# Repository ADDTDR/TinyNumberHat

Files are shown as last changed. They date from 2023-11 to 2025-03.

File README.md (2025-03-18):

# TinyNumberHat 

<!-- ![Alt text](TinyNumberHat_front.png)

![Alt text](TinyNumberHat_back.png)
  -->

Red ALS314         |  Green AL304V 
:-------------------------:|:-------------------------:
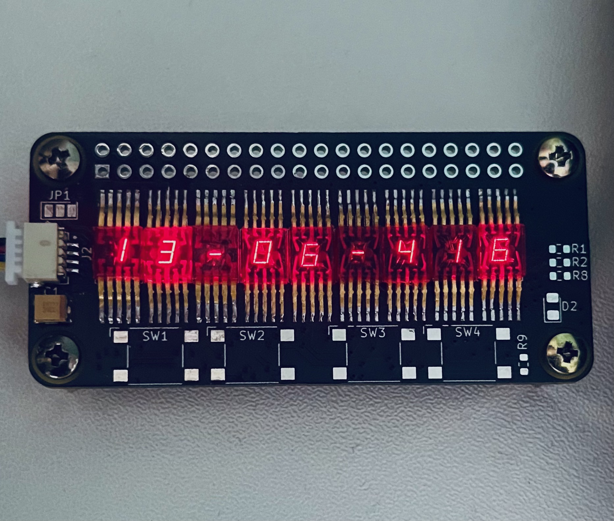
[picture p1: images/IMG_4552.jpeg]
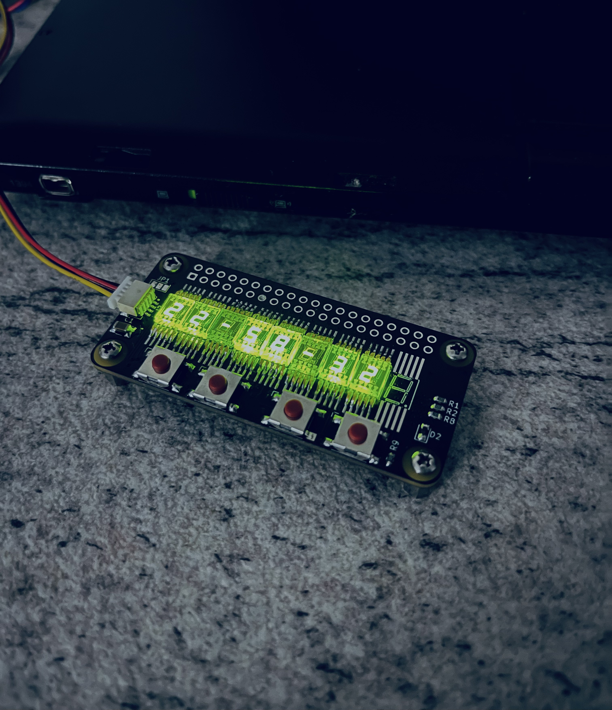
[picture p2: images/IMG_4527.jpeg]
  |  
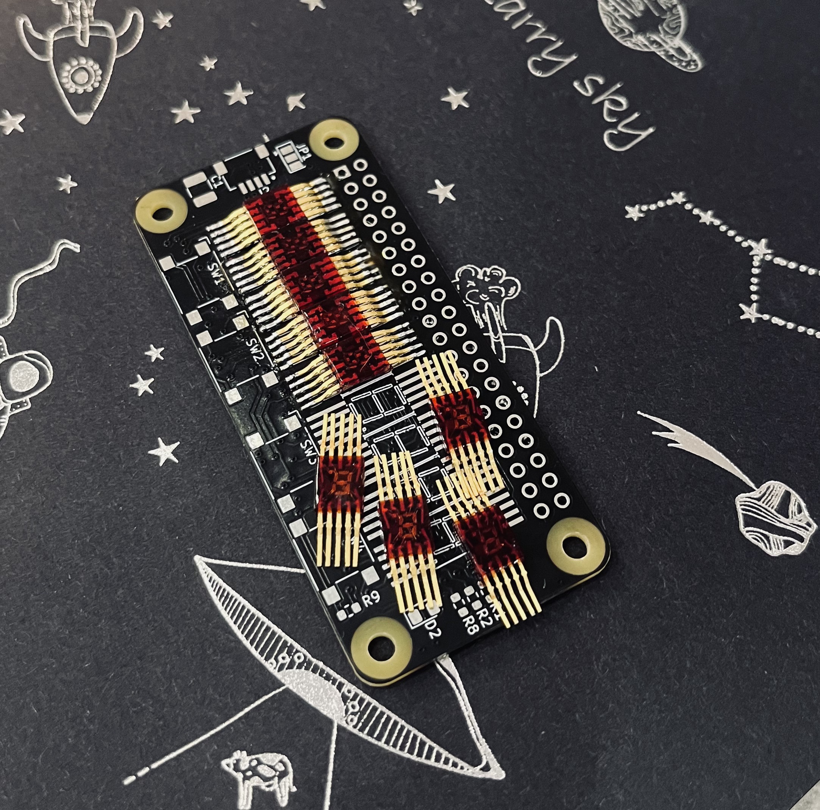
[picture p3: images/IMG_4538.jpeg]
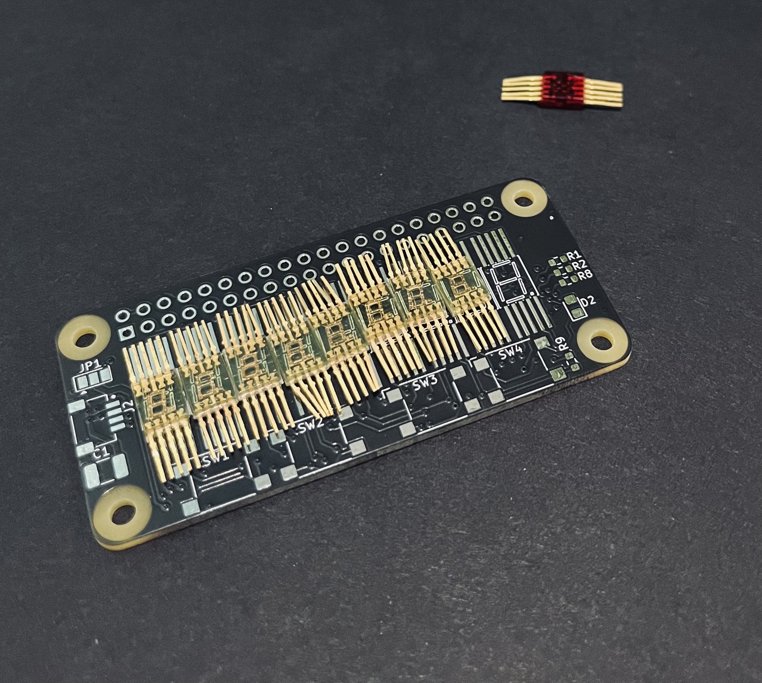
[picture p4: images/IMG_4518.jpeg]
                                                | 
<hr>
Clock example

<p float='left'>
    
    
</p>

<!-- # Build  -->

<!--img src="images/IMG_4520.jpeg" width="400"/-->

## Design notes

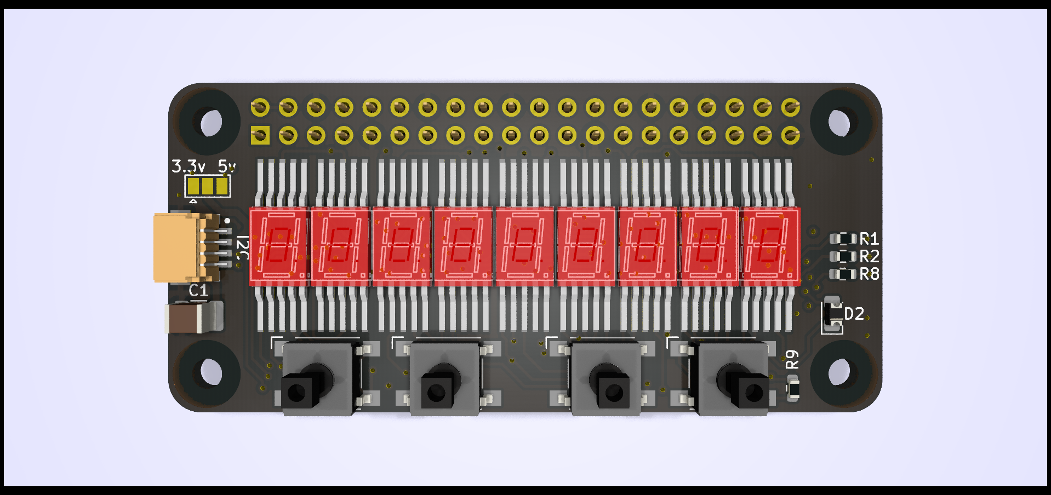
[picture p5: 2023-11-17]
images/TinyNumberHat_front.png

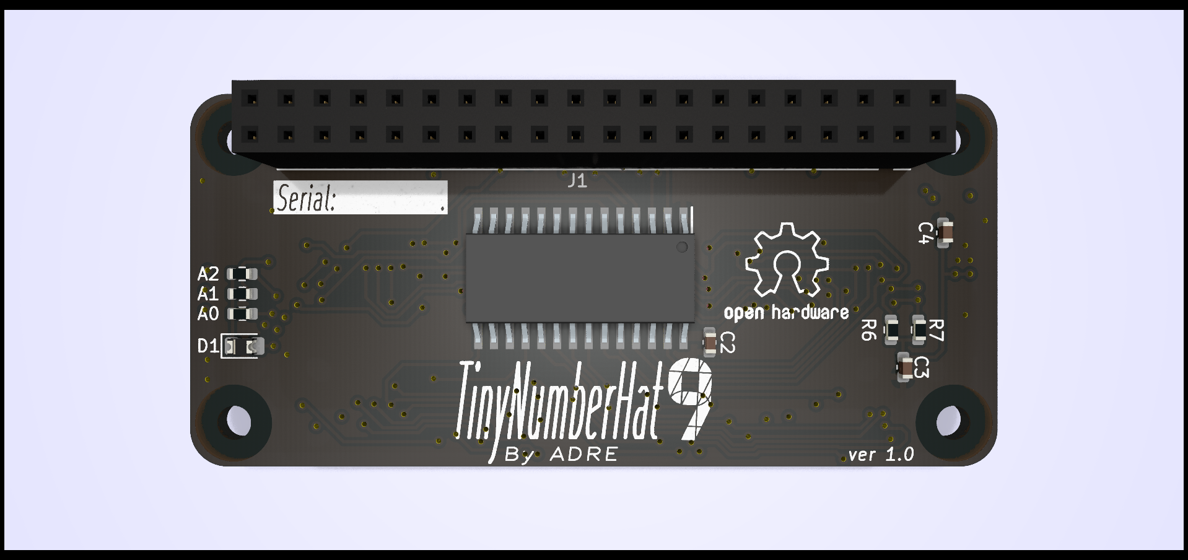
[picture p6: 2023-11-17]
images/TinyNumberHat_back.png

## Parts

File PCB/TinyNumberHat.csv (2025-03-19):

Reference | Qty | Value | DNP | Exclude from BOM | Exclude from Board | Footprint | Datasheet
C1 | 1 | 15uF |  |  |  | Capacitor_SMD:C_1210_3225Metric_Pad1.33x2.70mm_HandSolder | ~
C2,C3,C4 | 3 | 10uF |  |  |  | Capacitor_SMD:C_0603_1608Metric | ~
D1,D2 | 2 | 1N4148 |  |  |  | Diode_SMD:D_0805_2012Metric_Pad1.15x1.40mm_HandSolder | ~
DPY1,DPY2,DPY3,DPY4,DPY5,DPY6,DPY7,DPY8,DPY9 | 9 | ALS314 |  |  |  | ALS314
IC1 | 1 | SamacSys_Parts_HT16K33-28SOP |  |  |  | Holtek:SOIC127P1031X264-28N | http://uk.rs-online.com/web/p/products/8850765
J1 | 1 | GPIO |  |  |  | Connector_PinSocket_2.54mm:PinSocket_2x20_P2.54mm_Vertical
J2 | 1 | SM04B-SRSS-TB(LF)(SN) |  |  |  | LTP-305G:JST_SM04B-SRSS-TB(LF)(SN)
JP1 | 1 | Jumper_3_Bridged12 |  |  |  | Jumper:SolderJumper-3_P1.3mm_Bridged12_Pad1.0x1.5mm | ~
R1,R2,R8,R9 | 4 | 33k |  |  |  | Resistor_SMD:R_0603_1608Metric | ~
R3,R4,R5,R6 | 4 | 47k |  |  |  | Resistor_SMD:R_0603_1608Metric | ~
R7 | 1 | 10k |  |  |  | Resistor_SMD:R_0603_1608Metric | ~
SW1,SW2,SW3,SW4 | 4 | SW_Omron_B3FS |  |  |  | Button_Switch_SMD:SW_SPST_Omron_B3FS-105xP | https://omronfs.omron.com/en_US/ecb/products/pdf/en-b3fs.pdf

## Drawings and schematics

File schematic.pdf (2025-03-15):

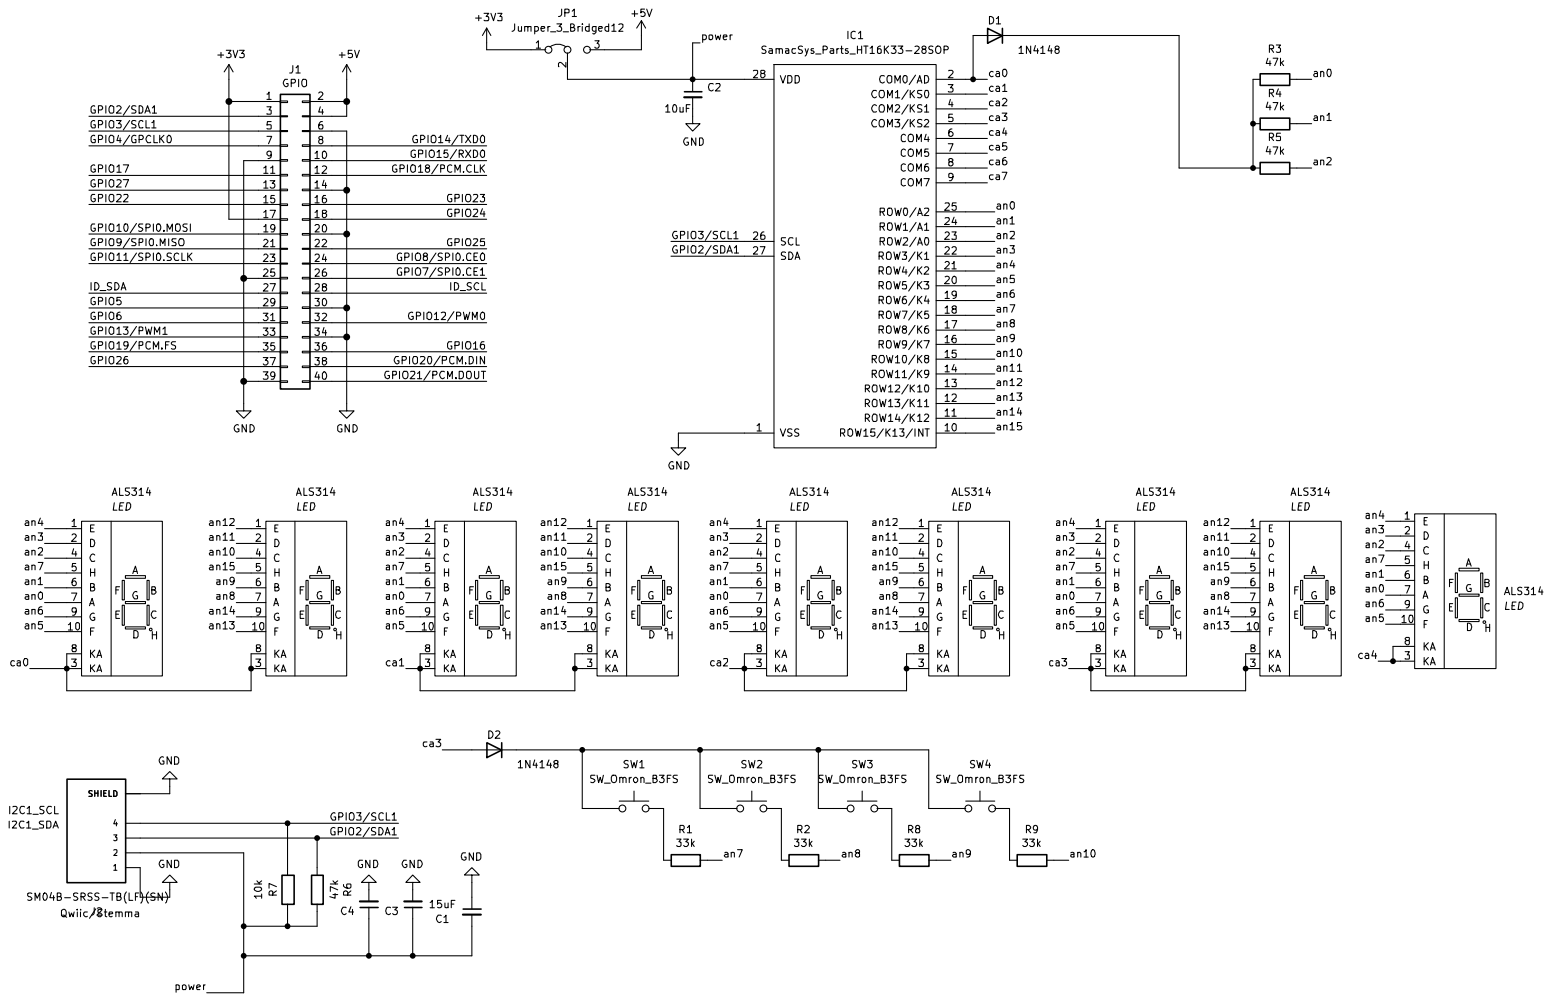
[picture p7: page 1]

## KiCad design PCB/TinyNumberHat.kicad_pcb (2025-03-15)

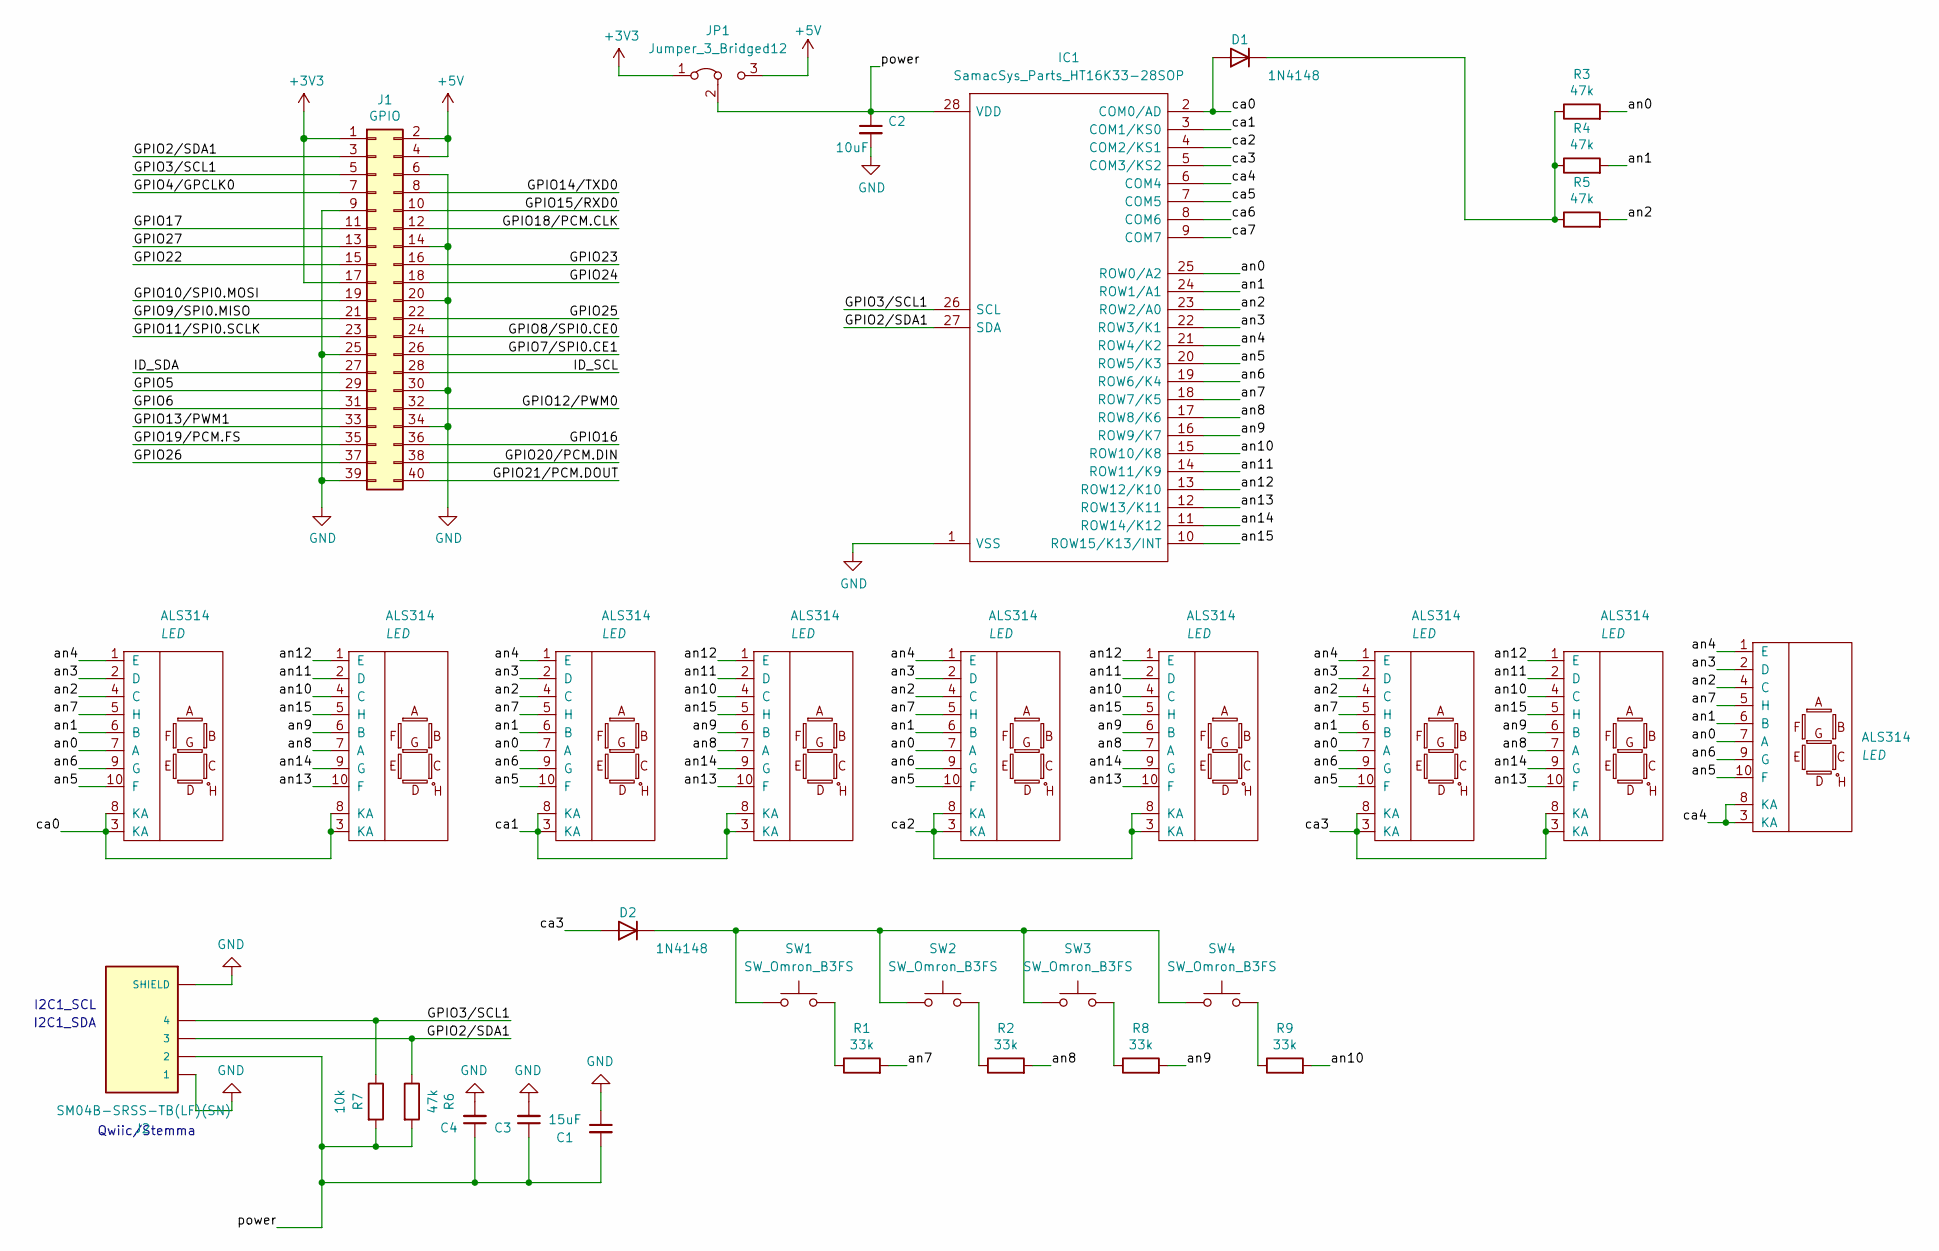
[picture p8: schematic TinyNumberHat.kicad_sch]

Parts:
C1: 15uF; C_1210_3225Metric_Pad1.33x2.70mm_HandSolder
C2, C3, C4: 10uF; C_0603_1608Metric
D1, D2: 1N4148; D_0805_2012Metric_Pad1.15x1.40mm_HandSolder
DPY1, DPY2, DPY3, DPY4, DPY5, DPY6, DPY7, DPY8, DPY9: ALS314
IC1: SamacSys_Parts_HT16K33-28SOP; SOIC127P1031X264-28N; Manufacturer_Part_Number HT16K33-28SOP
J1: GPIO; PinSocket_2x20_P2.54mm_Vertical
J2: SM04B-SRSS-TB(LF)(SN); JST_SM04B-SRSS-TB(LF)(SN); MPN SM04B-SRSS-TB(LF)(SN); Digi-Key_PN 455-1804-1-ND
JP1: Jumper_3_Bridged12; SolderJumper-3_P1.3mm_Bridged12_Pad1.0x1.5mm
R1, R2, R8, R9: 33k; R_0603_1608Metric
R3, R4, R5, R6: 47k; R_0603_1608Metric
R7: 10k; R_0603_1608Metric
SW1, SW2, SW3, SW4: SW_Omron_B3FS; SW_SPST_Omron_B3FS-105xP

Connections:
+3V3: J1.1, J1.17, JP1.1 (A)
+5V: J1.2, J1.4, JP1.3 (B)
/GPIO2/SDA1: IC1.27 (SDA), J1.3, J2.3, R6.1
/GPIO3/SCL1: IC1.26 (SCL), J1.5, J2.4, R7.1
/GPIO4/GPCLK0: J1.7
/GPIO5: J1.29
/GPIO6: J1.31
/GPIO7/SPI0.CE1: J1.26
/GPIO8/SPI0.CE0: J1.24
/GPIO9/SPI0.MISO: J1.21
/GPIO10/SPI0.MOSI: J1.19
/GPIO11/SPI0.SCLK: J1.23
/GPIO12/PWM0: J1.32
/GPIO13/PWM1: J1.33
/GPIO14/TXD0: J1.8
/GPIO15/RXD0: J1.10
/GPIO16: J1.36
/GPIO17: J1.11
/GPIO18/PCM.CLK: J1.12
/GPIO19/PCM.FS: J1.35
/GPIO20/PCM.DIN: J1.38
/GPIO21/PCM.DOUT: J1.40
/GPIO22: J1.15
/GPIO23: J1.16
/GPIO24: J1.18
/GPIO25: J1.22
/GPIO26: J1.37
/GPIO27: J1.13
/ID_SCL: J1.28
/ID_SDA: J1.27
/an0: DPY1.7 (A), DPY3.7 (A), DPY5.7 (A), DPY7.7 (A), DPY9.7 (A), IC1.25 (ROW0/A2), R3.2
/an1: DPY1.6 (B), DPY3.6 (B), DPY5.6 (B), DPY7.6 (B), DPY9.6 (B), IC1.24 (ROW1/A1), R4.2
/an2: DPY1.4 (C), DPY3.4 (C), DPY5.4 (C), DPY7.4 (C), DPY9.4 (C), IC1.23 (ROW2/A0), R5.2
/an3: DPY1.2 (D), DPY3.2 (D), DPY5.2 (D), DPY7.2 (D), DPY9.2 (D), IC1.22 (ROW3/K1)
/an4: DPY1.1 (E), DPY3.1 (E), DPY5.1 (E), DPY7.1 (E), DPY9.1 (E), IC1.21 (ROW4/K2)
/an5: DPY1.10 (F), DPY3.10 (F), DPY5.10 (F), DPY7.10 (F), DPY9.10 (F), IC1.20 (ROW5/K3)
/an6: DPY1.9 (G), DPY3.9 (G), DPY5.9 (G), DPY7.9 (G), DPY9.9 (G), IC1.19 (ROW6/K4)
/an7: DPY1.5 (H), DPY3.5 (H), DPY5.5 (H), DPY7.5 (H), DPY9.5 (H), IC1.18 (ROW7/K5), R1.2
/an8: DPY2.7 (A), DPY4.7 (A), DPY6.7 (A), DPY8.7 (A), IC1.17 (ROW8/K6), R2.2
/an9: DPY2.6 (B), DPY4.6 (B), DPY6.6 (B), DPY8.6 (B), IC1.16 (ROW9/K7), R8.2
/an10: DPY2.4 (C), DPY4.4 (C), DPY6.4 (C), DPY8.4 (C), IC1.15 (ROW10/K8), R9.2
/an11: DPY2.2 (D), DPY4.2 (D), DPY6.2 (D), DPY8.2 (D), IC1.14 (ROW11/K9)
/an12: DPY2.1 (E), DPY4.1 (E), DPY6.1 (E), DPY8.1 (E), IC1.13 (ROW12/K10)
/an13: DPY2.10 (F), DPY4.10 (F), DPY6.10 (F), DPY8.10 (F), IC1.12 (ROW13/K11)
/an14: DPY2.9 (G), DPY4.9 (G), DPY6.9 (G), DPY8.9 (G), IC1.11 (ROW14/K12)
/an15: DPY2.5 (H), DPY4.5 (H), DPY6.5 (H), DPY8.5 (H), IC1.10 (ROW15/K13/INT)
/ca0: D1.2 (A), DPY1.3 (KA), DPY1.8 (KA), DPY2.3 (KA), DPY2.8 (KA), IC1.2 (COM0/AD)
/ca1: DPY3.3 (KA), DPY3.8 (KA), DPY4.3 (KA), DPY4.8 (KA), IC1.3 (COM1/KS0)
/ca2: DPY5.3 (KA), DPY5.8 (KA), DPY6.3 (KA), DPY6.8 (KA), IC1.4 (COM2/KS1)
/ca3: D2.2 (A), DPY7.3 (KA), DPY7.8 (KA), DPY8.3 (KA), DPY8.8 (KA), IC1.5 (COM3/KS2)
/ca4: DPY9.3 (KA), DPY9.8 (KA), IC1.6 (COM4)
/ca5: IC1.7 (COM5)
/ca6: IC1.8 (COM6)
/ca7: IC1.9 (COM7)
/power: C1.2, C2.1, C3.1, C4.1, IC1.28 (VDD), J2.2, JP1.2 (C), R6.2, R7.2
GND: C1.1, C2.2, C3.2, C4.2, IC1.1 (VSS), J1.6, J1.9, J1.14, J1.20, J1.25, J1.30, J1.34, J1.39, J2.1, J2.S1 (SHIELD), J2.S2 (SHIELD)
unnamed: D1.1 (K), R3.1, R4.1, R5.1
unnamed: D2.1 (K), SW1.1, SW2.1, SW3.1, SW4.1
unnamed: R1.1, SW1.2
unnamed: R2.1, SW2.2
unnamed: R8.1, SW3.2
unnamed: R9.1, SW4.2

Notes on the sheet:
I2C1_SCL
I2C1_SDA
Qwiic/Stemma

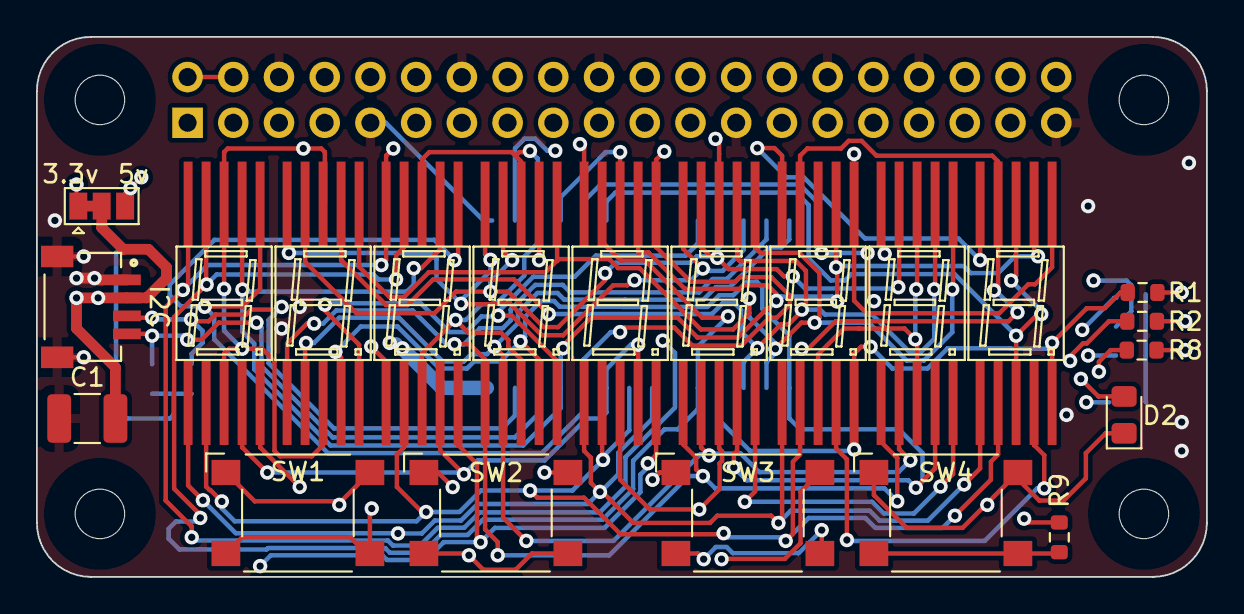
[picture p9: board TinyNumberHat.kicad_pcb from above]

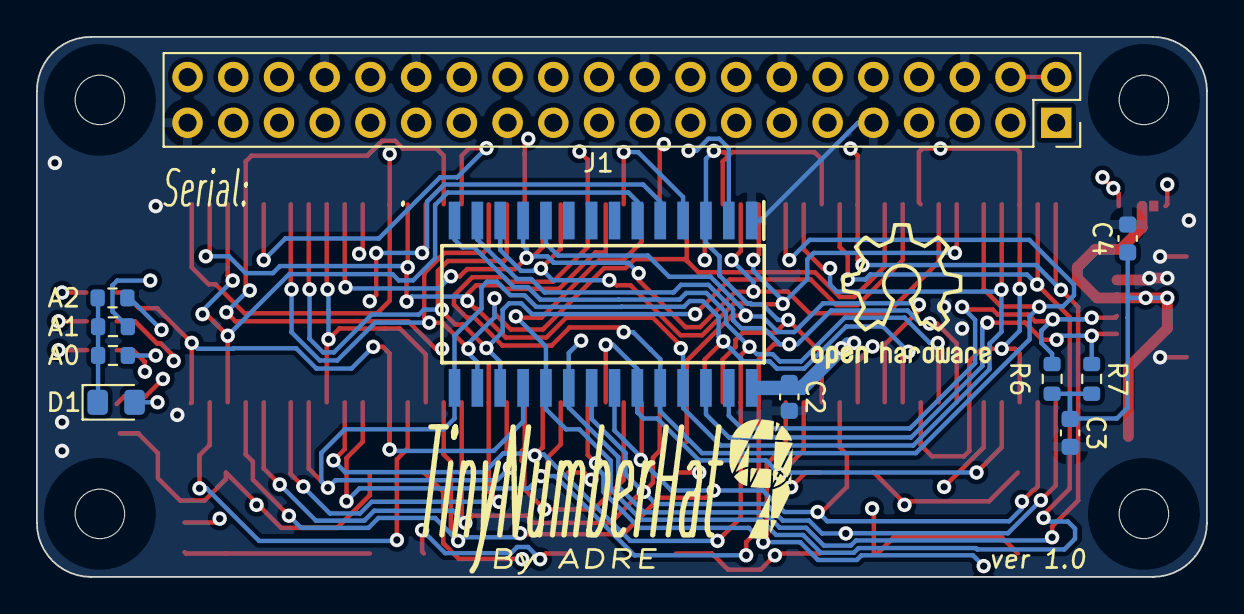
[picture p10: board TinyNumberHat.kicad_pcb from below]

Board: 4 copper layers, 65.0 x 30.0 mm, 32 parts (11 on the bottom side), 33 nets.

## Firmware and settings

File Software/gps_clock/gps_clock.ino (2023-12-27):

/**************************************************************************************
 * INCLUDE
 **************************************************************************************/

#include <ArduinoNmeaParser.h>
#include <Wire.h>



#define HT16K33_ADDRESS_0          0x70
#define HT16K33_TURN_ON_OSCILLATOR 0x21
#define HT16K33_ENABLE_DISPLAY     0x81
#define HT16K33_CMD_BRIGHTNESS     0xE0
#define LED_DRIVER_BRIGHTNESS_LEVEL 0x0F

class TinyNumberHat {
public:
  uint8_t const test_data[16] = {0b00111111, 0b00000110, 0b01011011, 0b01001111, 0b01100110, 0b01101101, 0b01111101, 0b00000111, 0b01111111, 0b01101111, 0xff, 0xff, 0xff, 0xff, 0xff, 0xff};
  uint8_t buffer[16];
  
  void begin() {
    Wire.begin(); // Initialize I2C
    ht16k33I2CAddress = HT16K33_ADDRESS_0;

    // Turn on oscillator
    Wire.beginTransmission(ht16k33I2CAddress);
    Wire.write(HT16K33_TURN_ON_OSCILLATOR);
    Wire.endTransmission();

    // Enable display (no blinking mode)
    Wire.beginTransmission(ht16k33I2CAddress);
    Wire.write(HT16K33_ENABLE_DISPLAY);
    Wire.endTransmission();

    // Clear display
    Wire.beginTransmission(ht16k33I2CAddress);
    Wire.write(0x00);
    for (int i = 0; i < 16; i++) {
      Wire.write(0x00);
    }
    Wire.endTransmission();

    // Set brightness 0-15
    Wire.beginTransmission(ht16k33I2CAddress);
    Wire.write(HT16K33_CMD_BRIGHTNESS | LED_DRIVER_BRIGHTNESS_LEVEL);
    Wire.endTransmission();

    // Fill with 1, turn on all segments
    Wire.beginTransmission(ht16k33I2CAddress);
    Wire.write(0x00);
    for (int i = 0; i < 16; i++) {
      Wire.write(0xFF);
    }
    Wire.endTransmission();

    delay(100); // Sleep for 5.1 seconds

    // Clear display
    Wire.beginTransmission(ht16k33I2CAddress);
    Wire.write(0x00);
    for (int i = 0; i < 16; i++) {
      Wire.write(0x00);
    }
    Wire.endTransmission();
  }

  void numericTest(){
      Wire.beginTransmission(ht16k33I2CAddress);
      Wire.write(0x00);
      for(int i = 0; i < 16; i ++){
        Wire.write(test_data[i]);
      }
      Wire.endTransmission();
  }

  void update(){
      Wire.beginTransmission(ht16k33I2CAddress);
      Wire.write(0x00);
      for(int i = 0; i < 16; i ++){
        Wire.write(buffer[i]);
      }
      Wire.endTransmission();
  }

  void clear(){
    Wire.beginTransmission(ht16k33I2CAddress);
    Wire.write(0x00);
    for(int i = 0; i < 16; i ++){
      Wire.write(0x00);
    }
    Wire.endTransmission();
  }

  
private:
  uint8_t ht16k33I2CAddress;
};


/**************************************************************************************
 * FUNCTION DECLARATION
 **************************************************************************************/

void onRmcUpdate(nmea::RmcData const);
void onGgaUpdate(nmea::GgaData const);

/**************************************************************************************
 * GLOBAL VARIABLES
 **************************************************************************************/

ArduinoNmeaParser parser(onRmcUpdate, onGgaUpdate);

TinyNumberHat tinyNumberHat;

/**************************************************************************************
 * SETUP/LOOP
 **************************************************************************************/

void setup()
{

  tinyNumberHat.begin();
  tinyNumberHat.numericTest();
  Serial.begin(9600);
  Serial1.begin(9600);
}

void loop()
{
  while (Serial1.available()) {
    parser.encode((char)Serial1.read());
  }
}

/**************************************************************************************
 * FUNCTION DEFINITION
 **************************************************************************************/

void onRmcUpdate(nmea::RmcData const rmc)
{
  Serial.print("RMC ");

  if      (rmc.source == nmea::RmcSource::GPS)     Serial.print("GPS");
  else if (rmc.source == nmea::RmcSource::GLONASS) Serial.print("GLONASS");
  else if (rmc.source == nmea::RmcSource::Galileo) Serial.print("Galileo");
  else if (rmc.source == nmea::RmcSource::GNSS)    Serial.print("GNSS");
  else if (rmc.source == nmea::RmcSource::BDS)     Serial.print("BDS");

  Serial.print(" ");
  Serial.print(rmc.time_utc.hour);
  int time_gmt = (rmc.time_utc.hour + 2) % 24;
  int tens = time_gmt / 10;      // tens now = 2
  int ones = time_gmt % 10;      // ones now = 6
  tinyNumberHat.buffer[0] = tinyNumberHat.test_data[tens];
  tinyNumberHat.buffer[1] = tinyNumberHat.test_data[ones];
  tinyNumberHat.buffer[2] = 0b01000000; // Add '-'
  

  Serial.print(":");
  Serial.print(rmc.time_utc.minute);
  tinyNumberHat.buffer[3] = tinyNumberHat.test_data[rmc.time_utc.minute / 10]; // tens 
  tinyNumberHat.buffer[4] = tinyNumberHat.test_data[rmc.time_utc.minute % 10]; // ones 
  tinyNumberHat.buffer[5] = 0b01000000; // Add '-'

  Serial.print(":");
  Serial.print(rmc.time_utc.second);
  tinyNumberHat.buffer[6] = tinyNumberHat.test_data[rmc.time_utc.second / 10];
  tinyNumberHat.buffer[7] = tinyNumberHat.test_data[rmc.time_utc.second % 10];
  tinyNumberHat.buffer[7] = tinyNumberHat.buffer[7] | 0b10000000; //  Add '.'
  

  Serial.print(".");
  Serial.print(rmc.time_utc.microsecond);
  tinyNumberHat.buffer[8] = tinyNumberHat.test_data[rmc.time_utc.microsecond];
  tinyNumberHat.update();

  if (rmc.is_valid)
  {
    Serial.print(" : LON ");
    Serial.print(rmc.longitude);
    Serial.print(" ° | LAT ");
    Serial.print(rmc.latitude);
    Serial.print(" ° | VEL ");
    Serial.print(rmc.speed);
    Serial.print(" m/s | HEADING ");
    Serial.print(rmc.course);
    Serial.print(" °");
  }

  Serial.println();
}

void onGgaUpdate(nmea::GgaData const gga)
{
  Serial.print("GGA ");

  if      (gga.source == nmea::GgaSource::GPS)     Serial.print("GPS");
  else if (gga.source == nmea::GgaSource::GLONASS) Serial.print("GLONASS");
  else if (gga.source == nmea::GgaSource::Galileo) Serial.print("Galileo");
  else if (gga.source == nmea::GgaSource::GNSS)    Serial.print("GNSS");
  else if (gga.source == nmea::GgaSource::BDS)     Serial.print("BDS");

  Serial.print(" ");
  Serial.print(gga.time_utc.hour);
  Serial.print(":");
  Serial.print(gga.time_utc.minute);
  Serial.print(":");
  Serial.print(gga.time_utc.second);
  Serial.print(".");
  Serial.print(gga.time_utc.microsecond);

  if (gga.fix_quality != nmea::FixQuality::Invalid)
  {
    Serial.print(" : LON ");
    Serial.print(gga.longitude);
    Serial.print(" ° | LAT ");
    Serial.print(gga.latitude);
    Serial.print(" ° | Num Sat. ");
    Serial.print(gga.num_satellites);
    Serial.print(" | HDOP =  ");
    Serial.print(gga.hdop);
    Serial.print(" m | Altitude ");
    Serial.print(gga.altitude);
    Serial.print(" m | Geoidal Separation ");
    Serial.print(gga.geoidal_separation);
    Serial.print(" m");
  }

  Serial.println();
}

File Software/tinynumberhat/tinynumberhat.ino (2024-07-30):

#include <Wire.h>
#include <unordered_map>

#define HT16K33_ADDRESS_0          0x70
#define HT16K33_TURN_ON_OSCILLATOR 0x21
#define HT16K33_ENABLE_DISPLAY     0x81
#define HT16K33_CMD_BRIGHTNESS     0xE0
#define LED_DRIVER_BRIGHTNESS_LEVEL 0x0F

class TinyNumberHat {
public:
   std::unordered_map<char, uint8_t> numbers = {
         {'0', 0b00111111},
        {'1', 0b00000110},
        {'2', 0b01011011},
        {'3', 0b01001111},
        {'4', 0b01100110},
        {'5', 0b01101101},
        {'6', 0b01111101},
        {'7', 0b00000111},
        {'8', 0b01111111},
        {'9', 0b01101111},
        {'.', 0b10000000},
        {'P', 0b01110011},
        {'L', 0b00111000},
        {'A', 0b01110111},
        {'Y', 0b01101110},
        {'S', 0b01101101},
        {'T', 0b01111000},
        {'O', 0b00111111}, // Corrected to 0b00111111
        {'U', 0b00111110},
        {'E', 0b01111001},
        {' ', 0b00000000},
        {'H', 0b01110110},
        {'-', 0b01000000},
        {'B', 0b01111100},
        {'C', 0b00111001},
        {'D', 0b01011110},
        {'F', 0b01110001},
        {'G', 0b01111101},
        {'I', 0b00000110},
        {'J', 0b00011110},
        {'K', 0b01110101}, // Representation for K
        {'M', 0b01010100}, // Representation for M
        {'N', 0b01010100}, // Representation for N
        {'Q', 0b01101011}, // Representation for Q
        {'R', 0b01010000}, // Representation for R
        {'V', 0b00111110},
        {'W', 0b00101010}, // Representation for W
        {'X', 0b01110110}, // Same as H
        {'Z', 0b01011011}, // Same as 2
        {'!', 0b10000110}, // Representation for !
        {'?', 0b01010011}, // Representation for ?
        {'*', 0b01100011}, // Representation for *
        {'#', 0b01111100}, // Representation for #
        {'$', 0b01101101}  // Representation for $
    };

  uint8_t charToBin(char ch){
    auto it = numbers.find(ch);
    if (it != numbers.end()) {
        return it->second;
    } else {
        // Default to 0 for unknown characters
        return 0;
    }
  }

  void begin() {
    Wire.begin(); // Initialize I2C
    ht16k33I2CAddress = HT16K33_ADDRESS_0;

    // Turn on oscillator
    Wire.beginTransmission(ht16k33I2CAddress);
    Wire.write(HT16K33_TURN_ON_OSCILLATOR);
    Wire.endTransmission();

    // Enable display (no blinking mode)
    Wire.beginTransmission(ht16k33I2CAddress);
    Wire.write(HT16K33_ENABLE_DISPLAY);
    Wire.endTransmission();

    // Clear display
    Wire.beginTransmission(ht16k33I2CAddress);
    Wire.write(0x00);
    for (int i = 0; i < 16; i++) {
      Wire.write(0x00);
    }
    Wire.endTransmission();

    // Set brightness 0-15
    Wire.beginTransmission(ht16k33I2CAddress);
    Wire.write(HT16K33_CMD_BRIGHTNESS | LED_DRIVER_BRIGHTNESS_LEVEL);
    Wire.endTransmission();

    // Fill with 1, turn on all segments
    Wire.beginTransmission(ht16k33I2CAddress);
    Wire.write(0x00);
    for (int i = 0; i < 16; i++) {
      Wire.write(0xFF);
    }
    Wire.endTransmission();

    delay(100); // Sleep for 5.1 seconds

    // Clear display
    Wire.beginTransmission(ht16k33I2CAddress);
    Wire.write(0x00);
    for (int i = 0; i < 16; i++) {
      Wire.write(0x00);
    }
    Wire.endTransmission();
  }

  void displayString(const char* str) {
    Wire.beginTransmission(ht16k33I2CAddress);
    Wire.write(0x00);
    for (int i = 0; i < 9; i++) {
      if (str[i] != '\0') {
        Wire.write(charToBin(str[i]));
      } else {
        Wire.write(0x00); // Write blank if string is shorter than 9 chars
      }
      // Wire.write(0x00); // Space between characters
    }
    Wire.endTransmission();
  }


    void displayDots() {
        for (int i = 0; i < 16; i++) {
            Wire.beginTransmission(ht16k33I2CAddress);
            Wire.write(0x00);
            for (int j = 0; j < 16; j++) {
                Wire.write((j == i) ? 0x80 : 0x00);
            }
            Wire.endTransmission();
            delay(100); // Delay between each dot
        }
    }

   void snakeAnimation() {
        uint8_t snake[16] = {0};
        for (int i = 0; i < 16; i++) {
            snake[i] = 0x01 << i;
            Wire.beginTransmission(ht16k33I2CAddress);
            Wire.write(0x00);
            for (int j = 0; j < 16; j++) {
                Wire.write(snake[j]);
            }
            Wire.endTransmission();
            delay(100); // Delay between each step of the snake
            snake[i] = 0x00;
        }
    }

private:
  uint8_t ht16k33I2CAddress;
};

TinyNumberHat tinyNumberHat;

void setup() {
  tinyNumberHat.begin();
}

void loop() {
    const char* sequences[] = {
        "HELLO", "WORLD", "123456789", "PLAY", "GOODBYE", 
        "A1B2C3", "DOG", "CAT", "QWERTY", "SNAKE", 
        "JUMP", "KICK", "FROG", "ZEBRA", "NIGHT",
        "LIGHT", "HAPPY", "FUNNY", "F!G#H$"
    };
    for (int i = 0; i < sizeof(sequences)/sizeof(sequences[0]); i++) {
        tinyNumberHat.displayString(sequences[i]);
        delay(500); // Display each sequence for 0.5 seconds
    }
  tinyNumberHat.displayDots();
  tinyNumberHat.snakeAnimation();
}

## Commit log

2023-11-03 Version 1.0
    [TinyNumberHat.kicad_pcb, TinyNumberHat.kicad_sch]
2023-11-13 Update silkscreens
    [TinyNumberHat-B_Courtyard.gbr, TinyNumberHat-B_Cu.gbl, TinyNumberHat-B_Mask.gbs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]
2023-11-14 Minor updates
    [TinyNumberHat.kicad_pcb]
2023-11-17 Small updates
    [TinyNumberHat.kicad_pcb]
2023-12-15 Add arduino sketch
2023-12-15 Update pcb
    [TinyNumberHat.kicad_pcb]
2023-12-27 Add arduino gps clock usage example, and python sketch
2023-12-27 Add minimal gps clock from gnrmc sence implementation for stm32g0 mcu
2024-07-30 Update arduino sketch
2025-03-15 Update to Kicad 9, add schematic
    [TinyNumberHat.kicad_pcb, TinyNumberHat.kicad_sch]
2025-03-19 Add bom file
    [TinyNumberHat.csv]
